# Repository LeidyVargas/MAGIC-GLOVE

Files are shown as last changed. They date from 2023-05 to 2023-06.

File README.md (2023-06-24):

Banner

# MAGIC-GLOVE
*Un proyecto que busca, que sea posible, controlar un juego con los simples movimientos de las manos;  por ello, sera usado para fines educativos y de entretenimiento, en donde mediante el juego y la diversion, las personas podran aprender.*

Nosotros Leidy Juliana Vargas Moreno, Emmanuel Bonilla Mitrotti y Juan Sebastian Torres Rodriguez; enfocados en cambiar y revolucionar la forma convencional con la que se juegan videojuegos, y que mediante la diversión se logre desarrollar una destreza y habilidad motora, además de aprender mientras se juega, vimos una necesidad que convertimos en el siguiente objetivo:

* Diseñar y construir un guante capaz de controlar un juego, mediante el transporte de señales e información, utilizando programación y circuitos electrónicos, con el fin de revolucionar la forma típica de controlar un videojuego.

De esta manera, cualquier persona podrá divertirse de una manera diferente a “presionar botones” y además, el guante también puede ser utilizado, para juegos educativos, en donde se fomente el aprendizaje, con la diversión. Solo es cuestión de adaptarlo. 

## **DIAGRAMA DE FLUJO SOLUCIÓN**
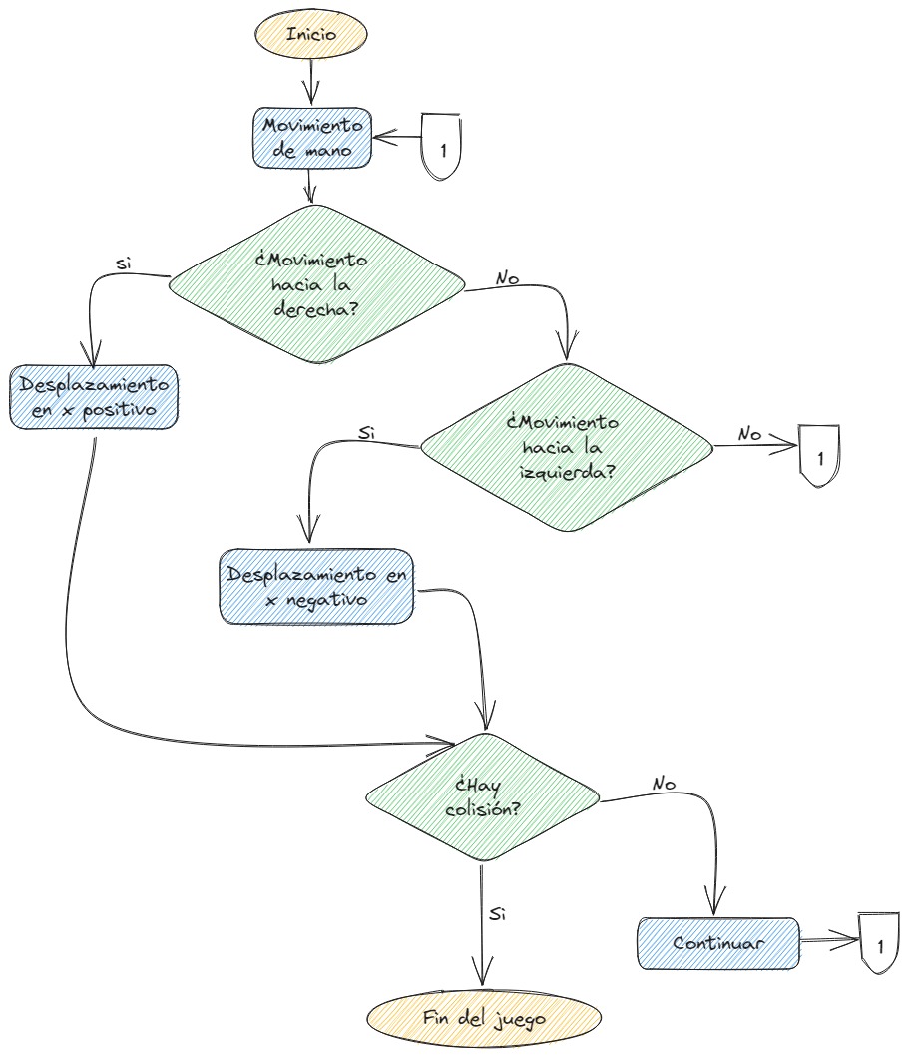
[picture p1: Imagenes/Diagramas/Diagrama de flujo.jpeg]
Diagrama de flujo Diagrama de Flujo


## **DIAGRAMA DE CAJA NEGRA**
Luego de ver el funcionamiento del guante, se establece un diagrama de cajas negras, en donde se busca definir lo que va a hacer este proyecto y lo que necesita, evaluado a su vez entradas y salidas, tanto de cada componente, como de energía.

En este primero se observa dicho diagrama, sin una tecnología definida:

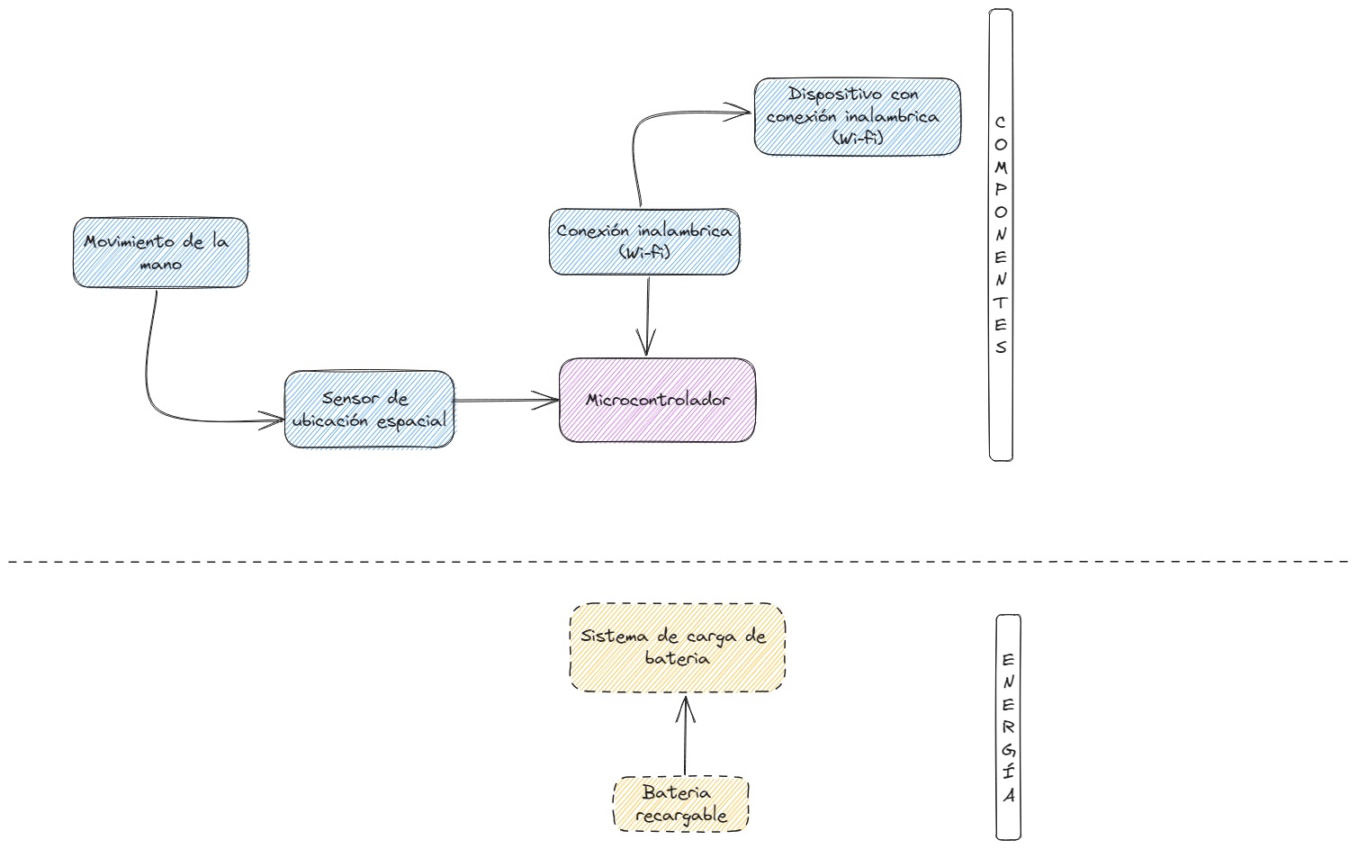
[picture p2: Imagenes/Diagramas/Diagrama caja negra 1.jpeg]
Diagrama de caja negra


Mientras que, en esta segunda imagen, se define una tecnología para cada una de las “cajas” evaluadas en el diagrama:

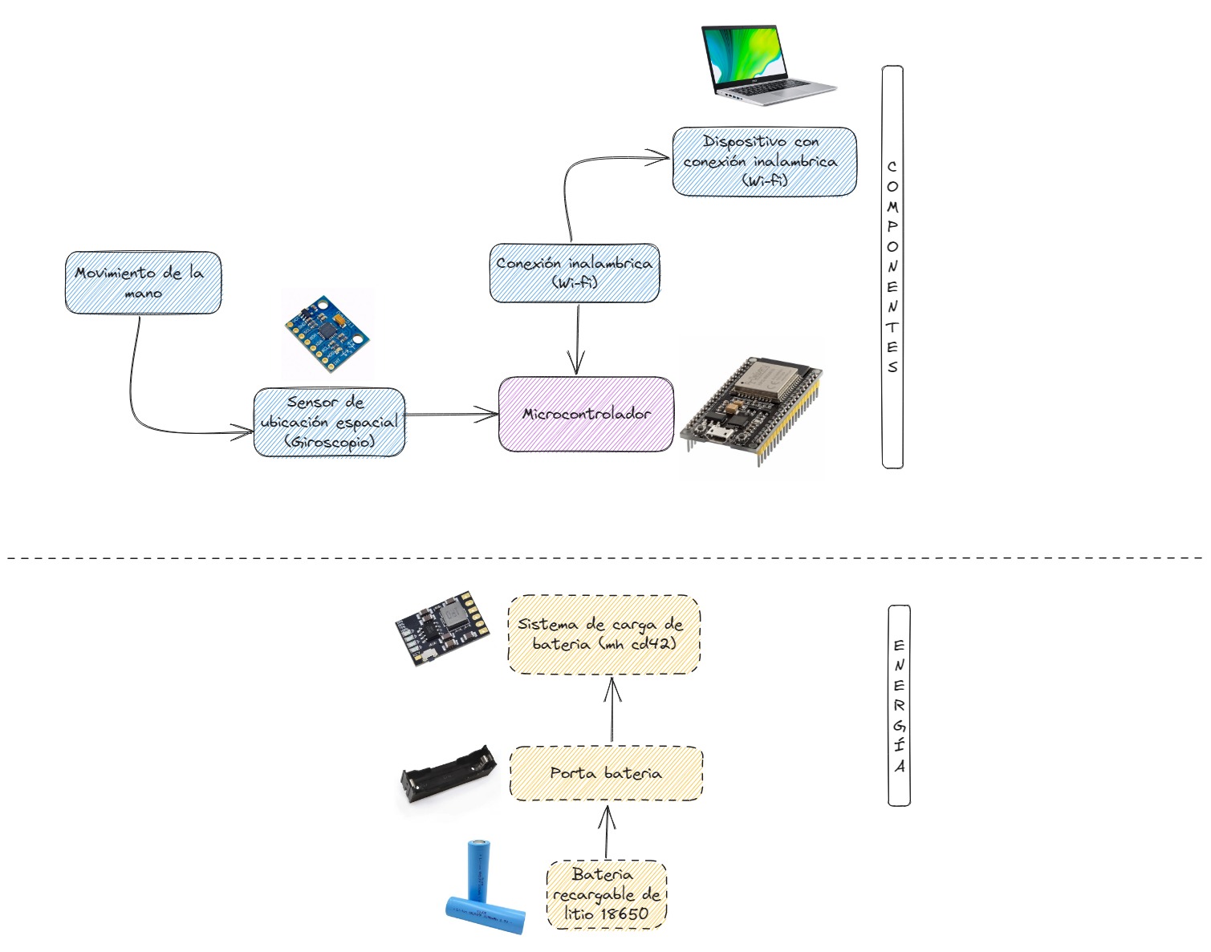
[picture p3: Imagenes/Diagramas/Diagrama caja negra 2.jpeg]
Diagrama de caja negra2


## **IMAGENES DE DISEÑOS EN EL SALON**
Conforme se avanzó en el proyecto, el profesor nos realizaba las respectivas correcciones y/o retroalimentaciones, en el tablero del salón; las cuales tenían que ver con la estructura del circuito, y se observan en las siguientes imágenes:

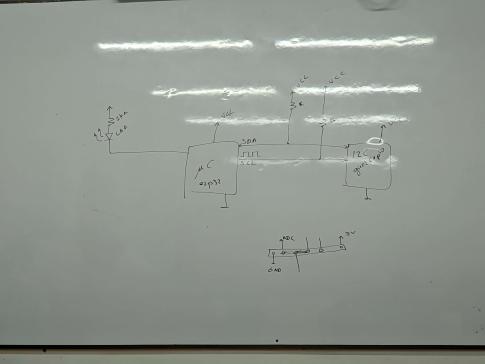
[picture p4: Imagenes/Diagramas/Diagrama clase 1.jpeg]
diseño en salon 1 Diseño en salon 1


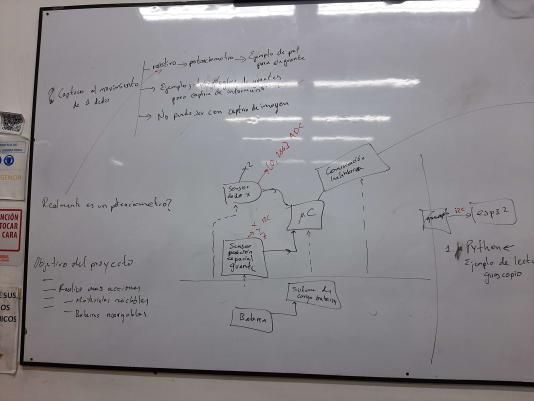
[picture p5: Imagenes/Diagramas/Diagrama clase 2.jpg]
diseño en salon 2 Diseño en salon 2


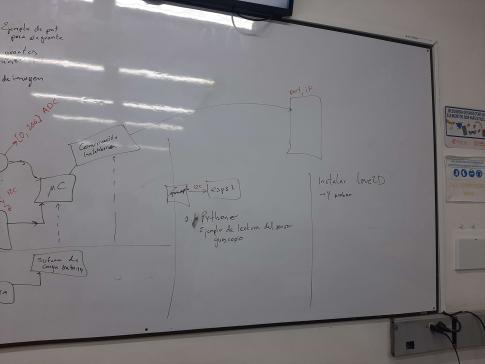
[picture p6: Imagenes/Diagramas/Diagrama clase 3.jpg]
diseño en salon 3 Diseño en salon 3


## **IMPLEMENTACIÓN**
En esta sección, se empieza  diseñar, construir y montar la parte electronica y fisica del guante, por lo cual se inicia creando el circuito que relaciona cada componente que contiene el mismo, quedando de la siguiente forma: 

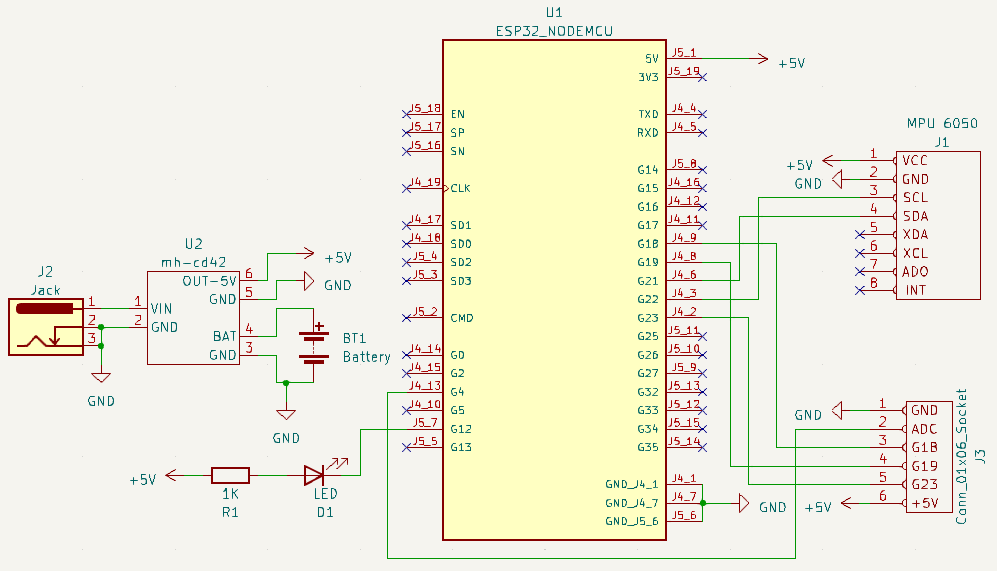
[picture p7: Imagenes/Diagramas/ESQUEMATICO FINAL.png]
Esquematico


Obtenido el circuito del proyecto, se empieza crear la placa de la PCB, en donde se realizan los caminos que conectan los componentes, asignando diferentes tamaños para señal, gnd y pines, utilizando el más grueso para el voltaje; los caminos se realizan en diferentes caras.

#### **Caminos de la cara frontal**
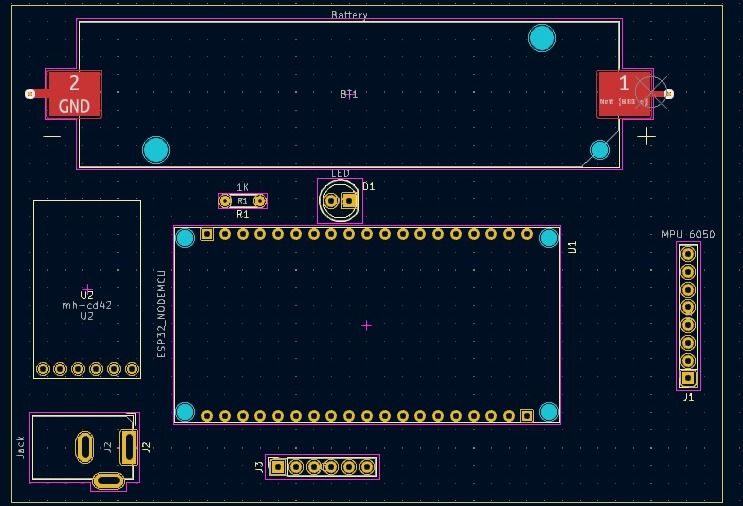
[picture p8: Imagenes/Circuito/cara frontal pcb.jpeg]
Cara Frontal

#### **Caminos de la cara trasera**
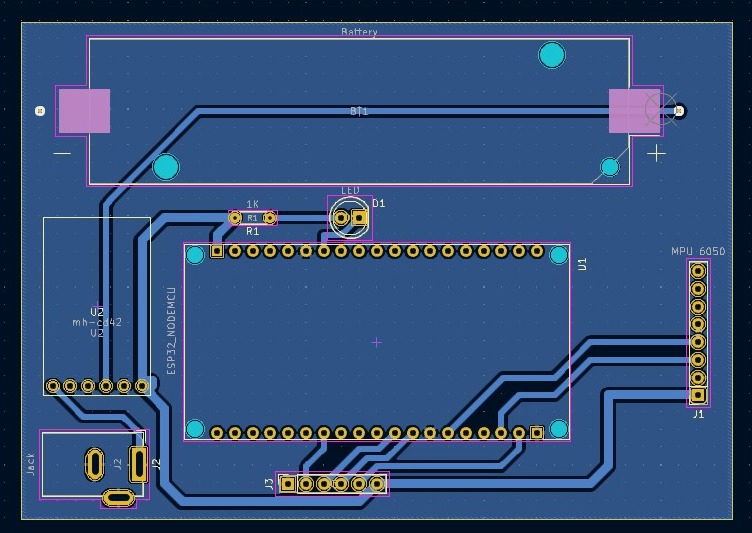
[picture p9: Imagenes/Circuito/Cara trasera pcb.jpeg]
Cara trasera


Se revisan cada uno de los posibles errores en el circuito, antes de considerarlo como resultado final, y realizado dicho proceso, se manda a construir la PCB en Yahiko electronica; 
con el archivo de los gerber que se encuentra en los archivos del GitHub como “Impresión de PCB (archivo)” . El resultado de la placa impresa se observa a continuación:

| | |
| --- |:---:|
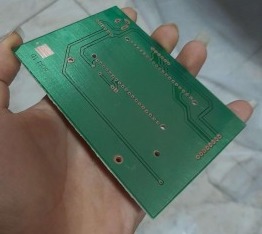
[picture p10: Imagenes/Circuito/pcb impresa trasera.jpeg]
Pcb impresa trasera
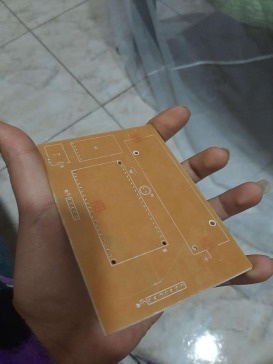
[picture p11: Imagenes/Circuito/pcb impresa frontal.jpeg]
Pcb impresa frontal
|  | |

Con la PCB, se procede a montar todo el circuito en ella, para así obtener el resultado final de la parte electrónica del proyecto.

| | |
| --- |:---:|
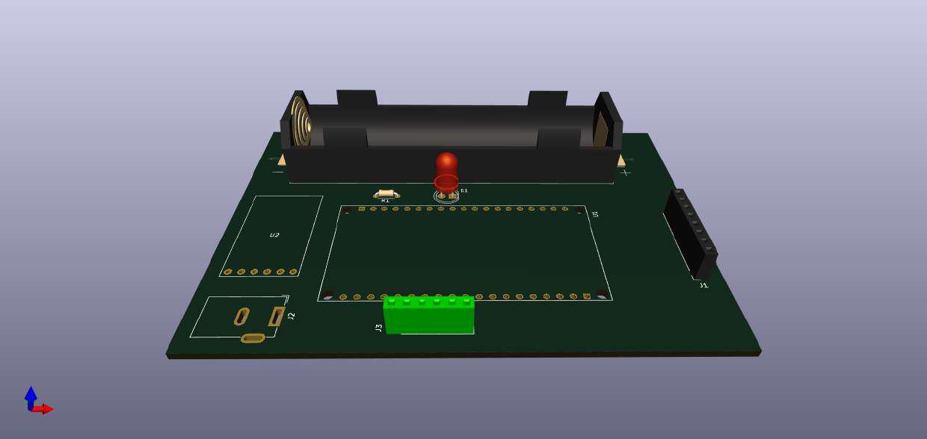
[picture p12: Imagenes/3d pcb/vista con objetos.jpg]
Pcb 3d
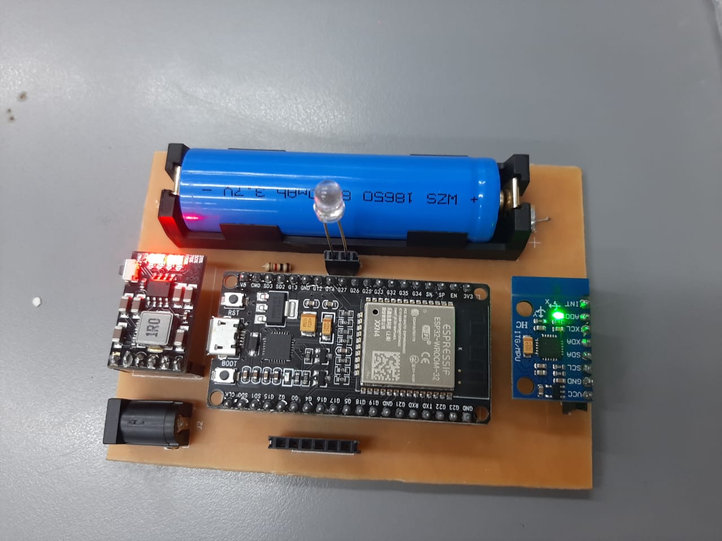
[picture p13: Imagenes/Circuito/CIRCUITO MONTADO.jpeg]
Circuito montado
| |  | 

## **PRUEBAS**

Para las pruebas, se dividieron en dos partes: De estructura y de programación:

La pruebas de estructura consisten en el corte láser, realizado para construir la caja del guante, que contiene la pcb, en donde para el primer intento de corte (archivo que se encuentra al inicio del GitHub), se genera una disminución en las medidas; lo cual se puede observar en la siguiente imagen, donde la figura de la derecha, fue en la que se alteraron las medidas, y la de la izquierda, es el resultado esperado (final). 

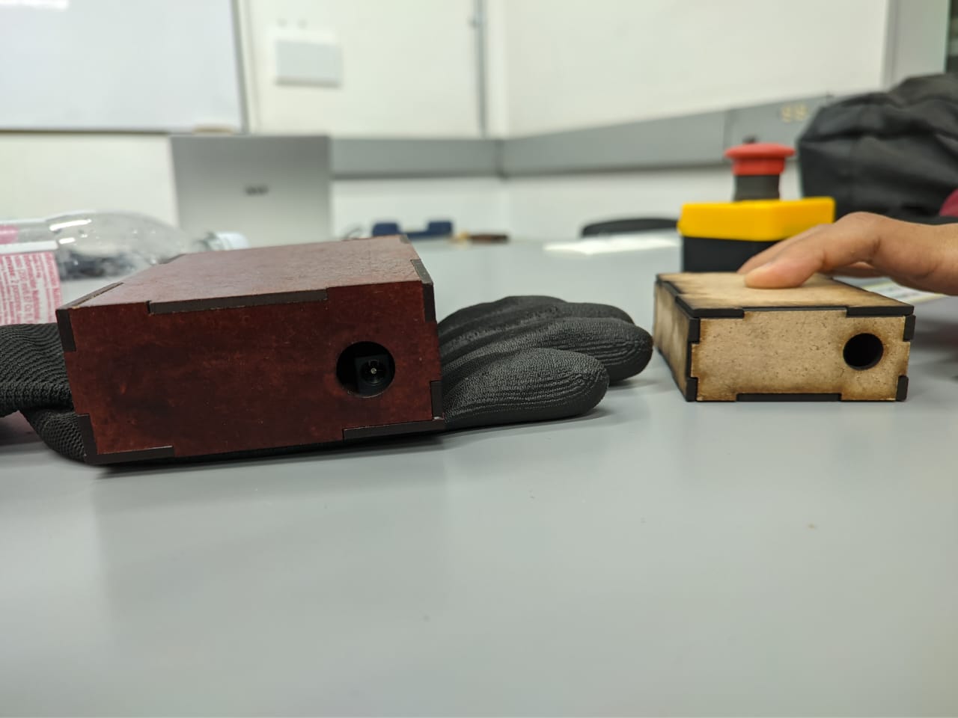
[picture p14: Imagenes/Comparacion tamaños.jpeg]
Comparacion


En el desarrollo del juego se abrió un socketUDP para poder recibir los datos del guante y asi poder mover la nave. 

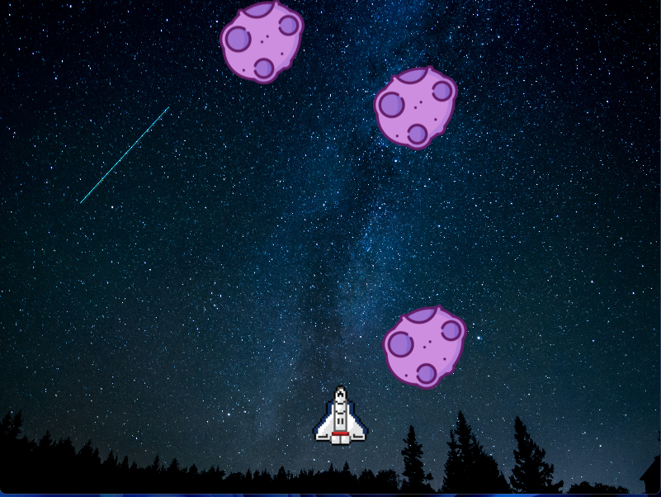
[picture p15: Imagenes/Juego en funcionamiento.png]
imagen Juego


Por otro lado, se realizaron diversas pruebas de programación, pues al principio no se recibieron correctamente los datos de movimiento del giroscopio, tal como se observa en el siguiente video; pues la nave se mueve hacia otro lado diferente del giroscopio, además de que no lograba conectarse al computador, [Link del video](./Videos/Juego%20y%20Guante%20.mp4)

Al final de las pruebas realizadas, se logra construir el guante y por tanto terminar el proyecto, el resultado y aplicación del guante, se puede observar en el siguiente video: [Link del video final. ](./Videos/PRUEBA%20DE%20FUNCIONAMIENTO.mp4)

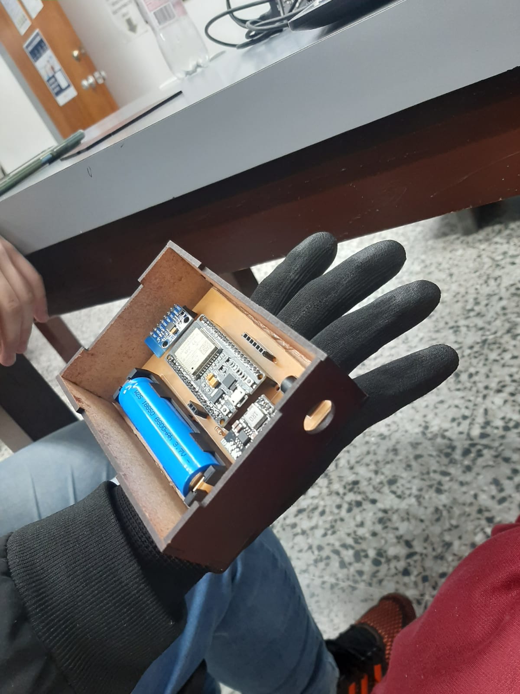
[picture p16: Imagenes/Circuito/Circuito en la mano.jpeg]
Guante en mano


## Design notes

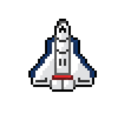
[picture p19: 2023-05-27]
Codigo-Juego/images/Nave.png

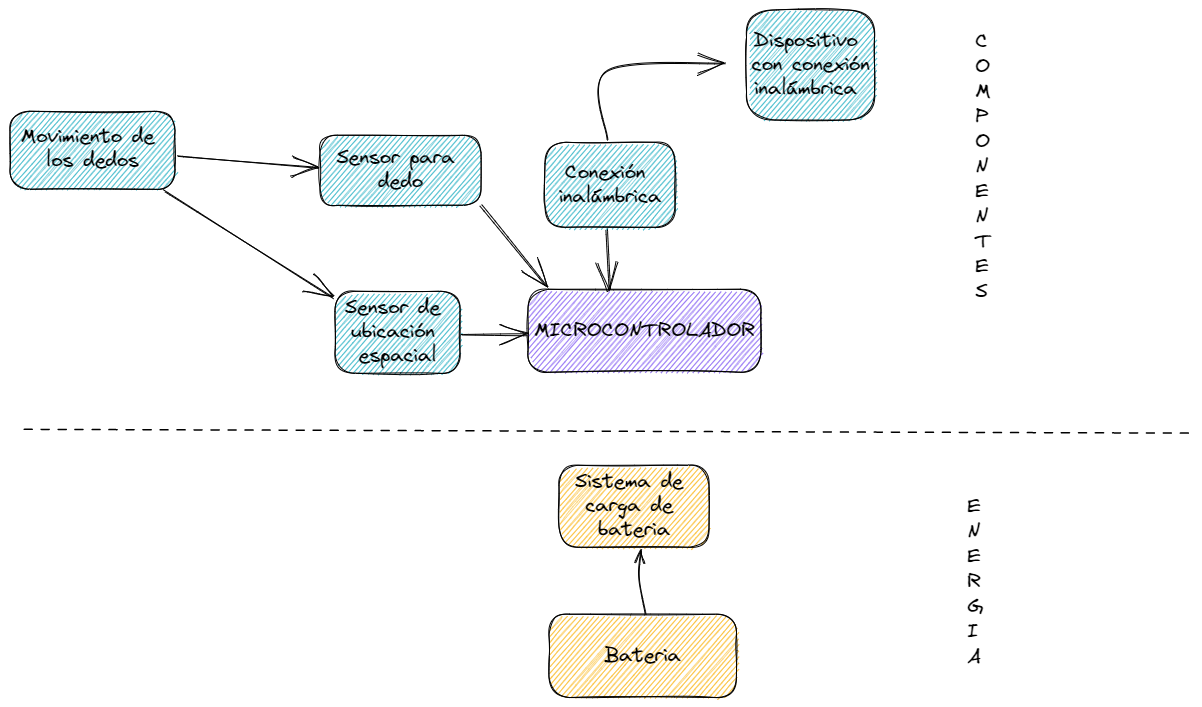
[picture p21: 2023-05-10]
Imagenes/Diagramas/DIAGRAMA CAJA NEGRA.png

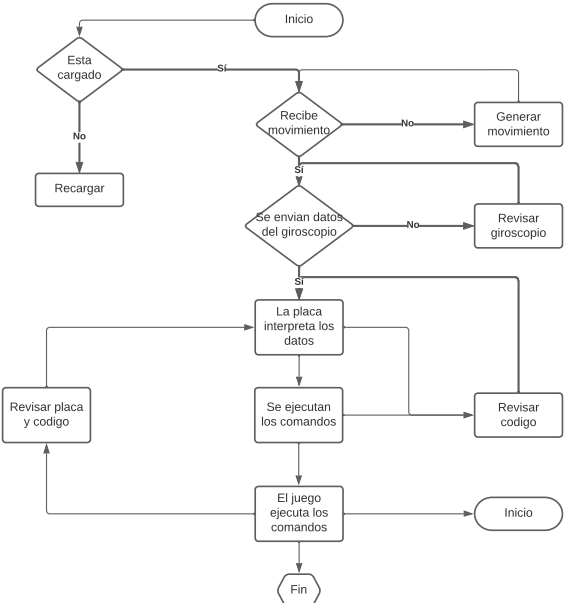
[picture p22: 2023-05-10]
Imagenes/Diagramas/DIAGRAMA DE FLUJO TECNICO.png

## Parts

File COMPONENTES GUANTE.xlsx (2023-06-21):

COMPONENTE | REFERENCIA | CANTIDAD | UNIDAD | PRECIO TOTAL | ¿Lo tenemos?
Tarjeta de desarrollo | Esp32 | 1 | $30000 | $30000 | SI
Giroscopio | MPU 6050 | 1 | $15000 | $15000 | SI
Baterias de litio recargables | 18650 | 1 | $14200 | $28000 | SI
Cargador de baterias de litio 18650 | mhcd42 (http://articulo.mercadolibre.com.co/MCO-917946237) | 1 | $9800 | $9800 | SI
Porta baterias | 18650 Soldadura SMD | 1 | $7000 | $7000 | SI
Jack power |  | 1 | $1000 | $1000 | SI
MDF | Madera mdf de 3 mm | 1 | No aplica |  | SI
TOTAL |  |  | $77000 | $90800

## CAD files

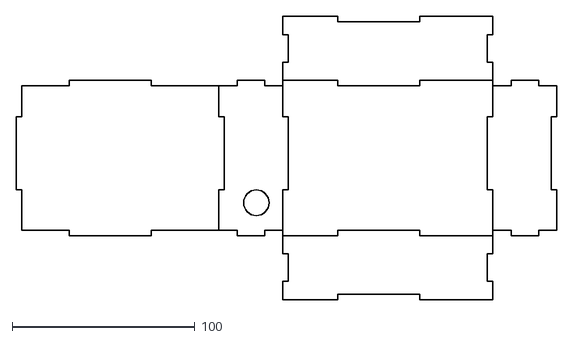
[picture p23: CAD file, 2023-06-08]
CORTE LASER.dxf
296.0 x 155.0

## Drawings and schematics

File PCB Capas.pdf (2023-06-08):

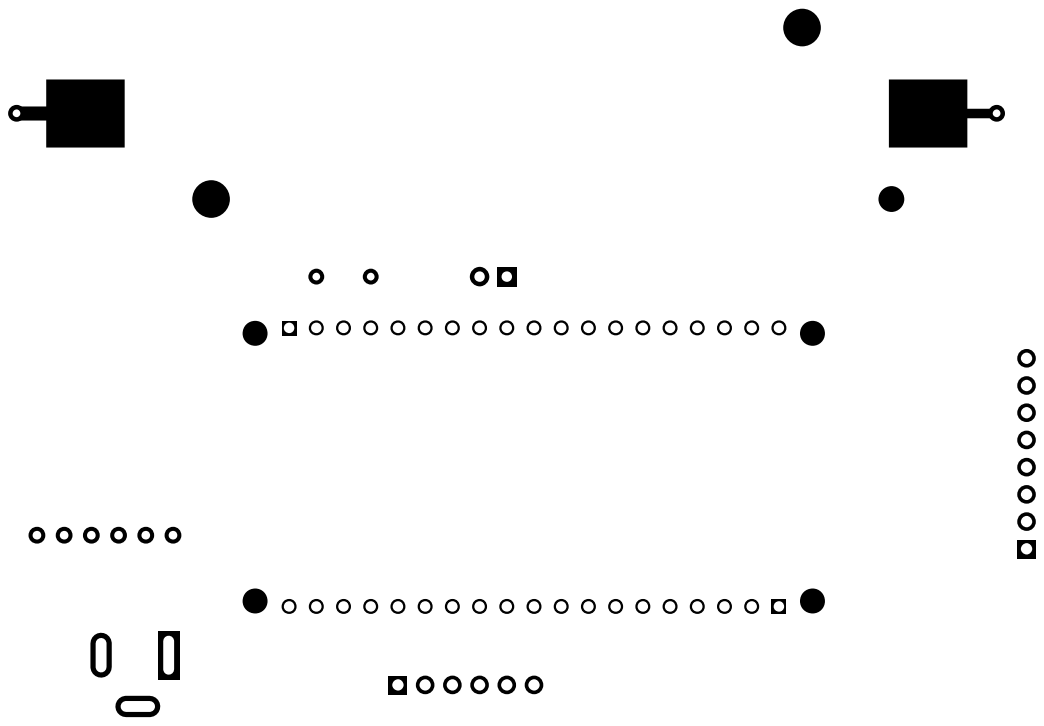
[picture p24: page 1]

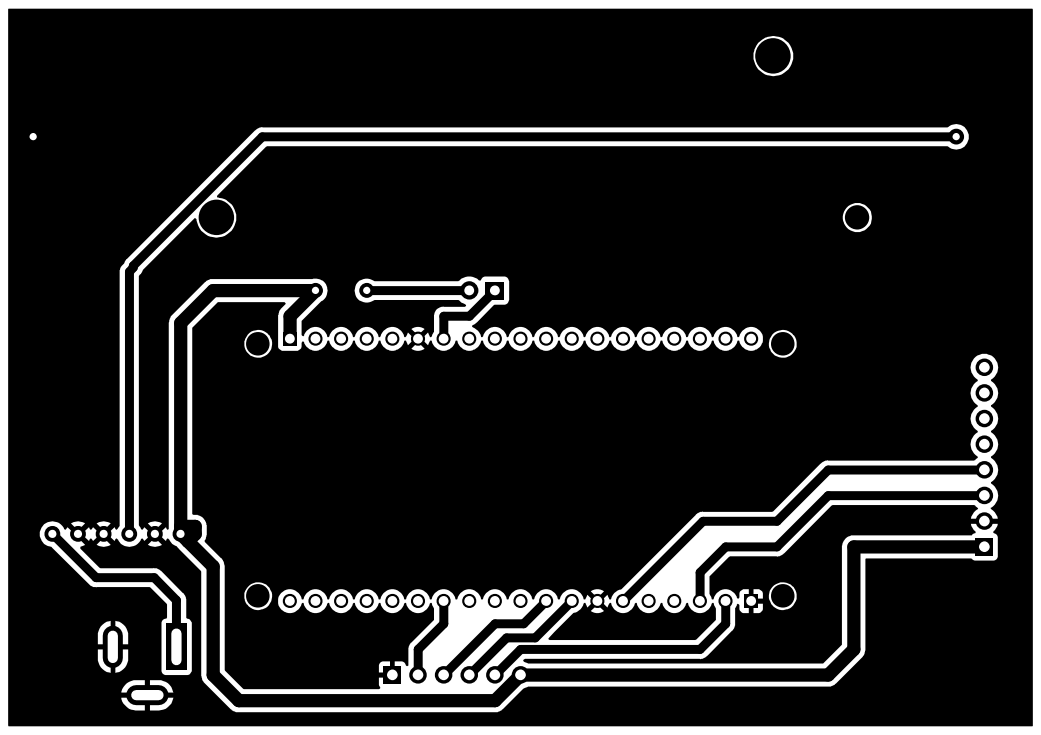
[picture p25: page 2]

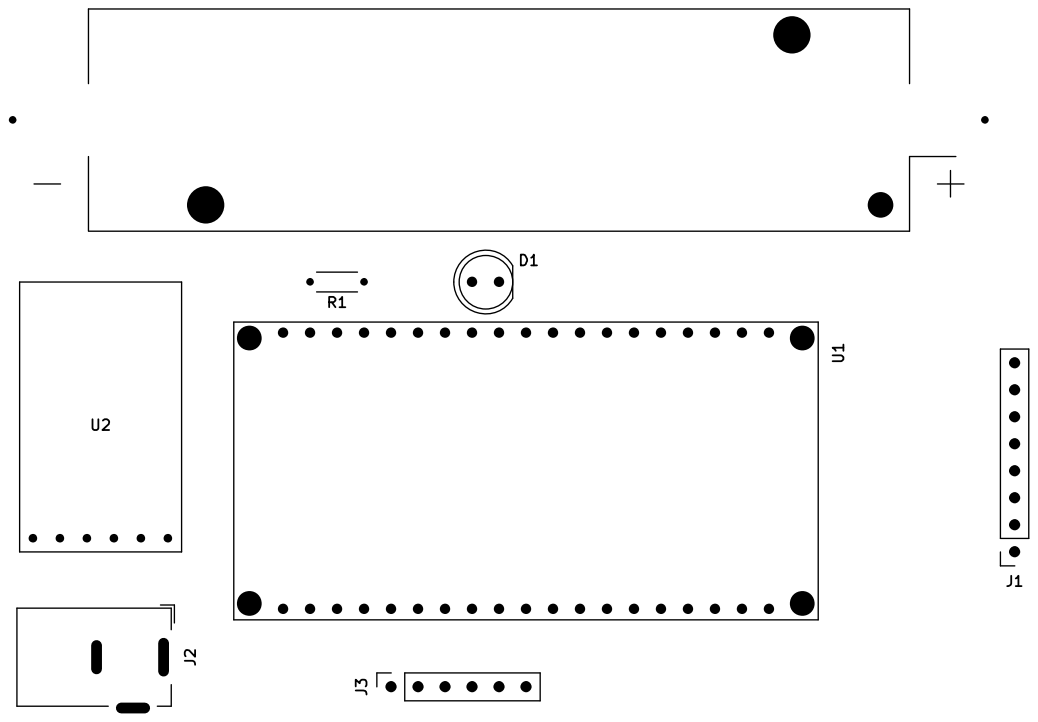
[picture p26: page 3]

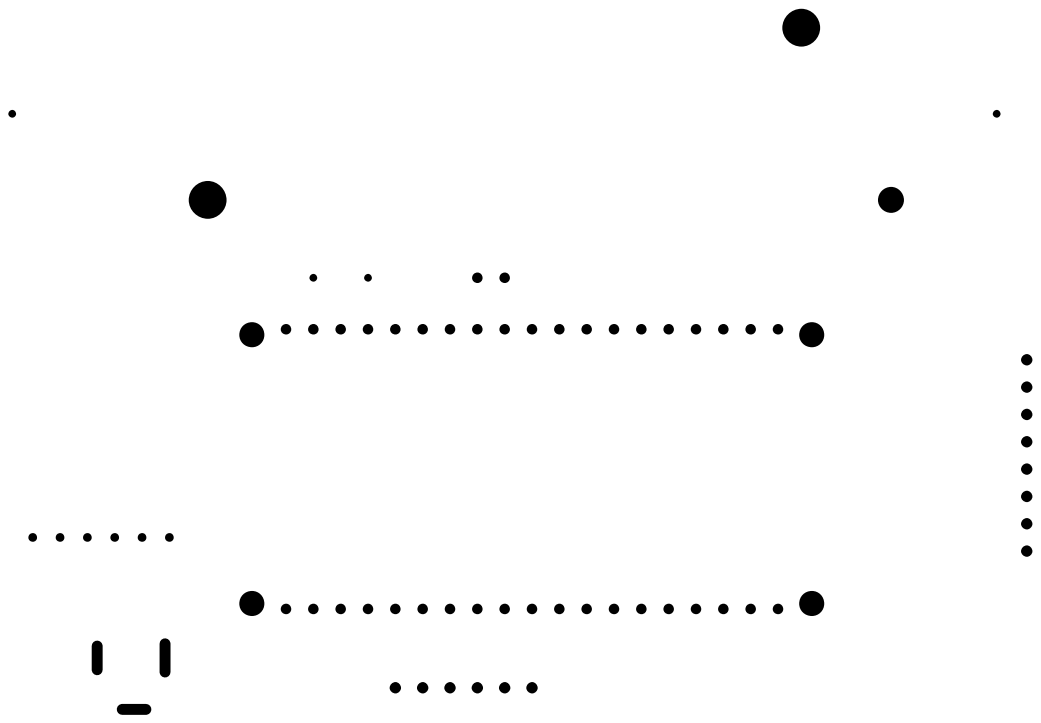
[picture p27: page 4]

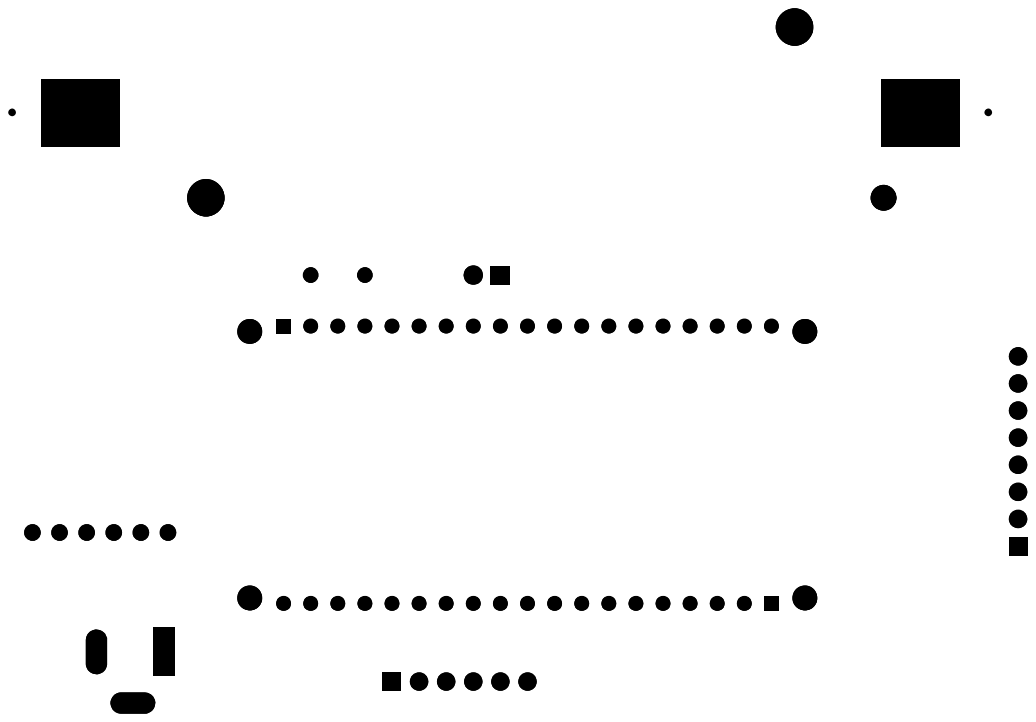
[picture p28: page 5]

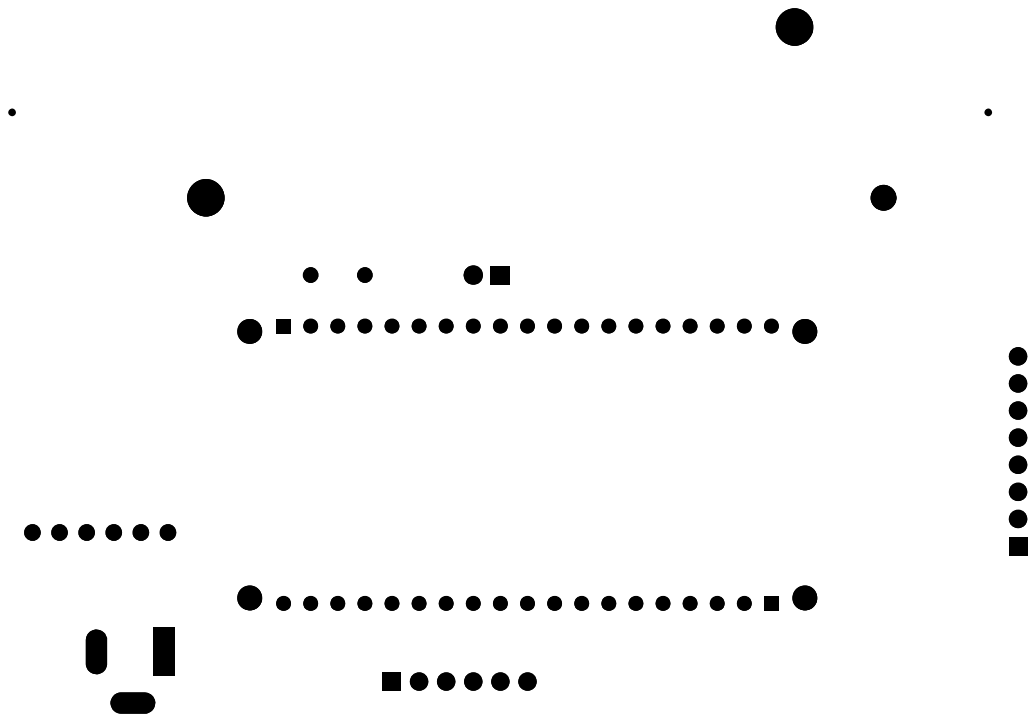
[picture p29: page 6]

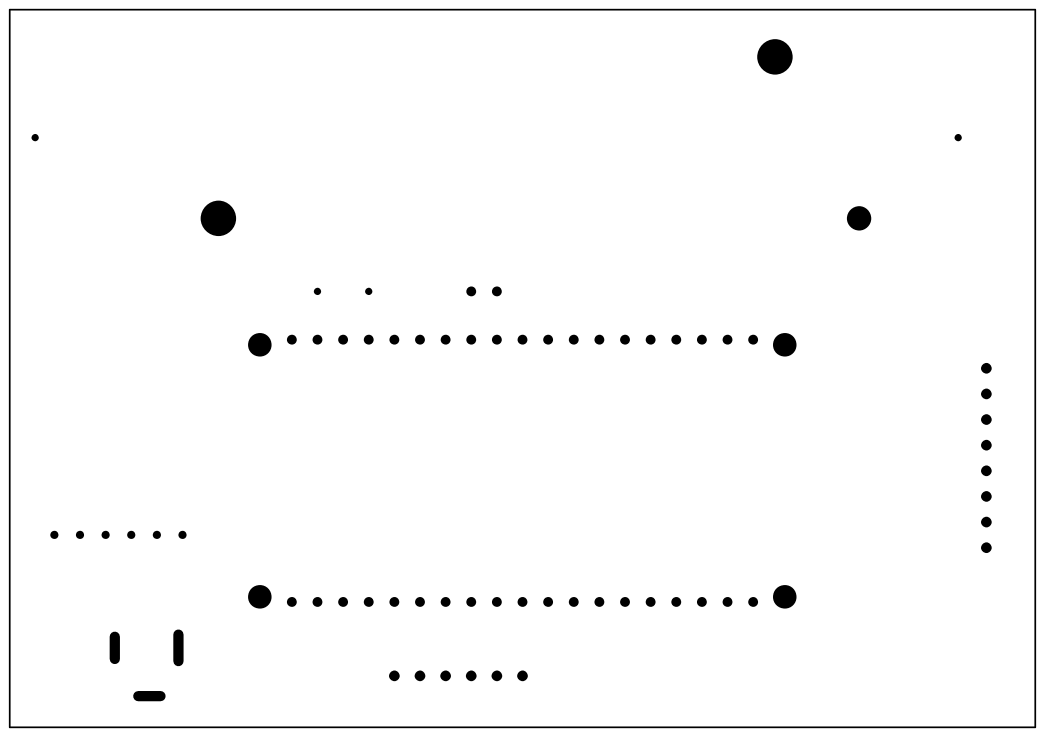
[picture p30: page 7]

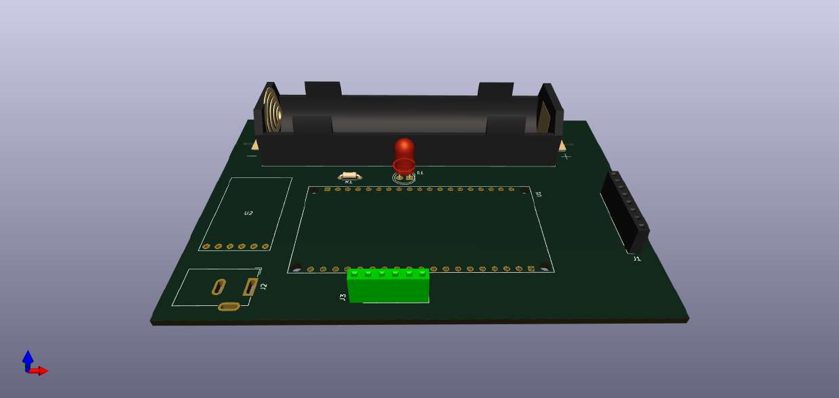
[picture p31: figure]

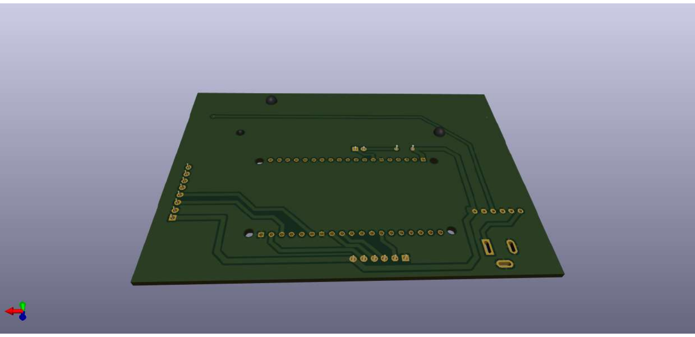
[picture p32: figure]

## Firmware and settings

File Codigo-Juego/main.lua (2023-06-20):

socket = require("socket")
Udp = socket.udp()
Udp:setsockname('192.168.12.8', 12345)
Udp:settimeout(0)

function love.load()
  -- carga e inicio de variables
  
  Object = require 'classic'
  require 'asteroide'
  -- controles
  
  gameOver = love.graphics.newImage('images/game-over.png')

  windowHeight = love.graphics.getHeight()
  windowWidth = love.graphics.getWidth()

  background = love.graphics.newImage('images/Cielo-estrellado.jpg')
  backgroundW = background:getWidth()
  backgroundH = background:getHeight()

  nave = love.graphics.newImage('images/Nave.png')
  naveWidth = 125
  naveHeight = 125
  
  posicionX = 350
  posicionY = 450
  
  hitBoxX = naveWidth/2 
  hitBoxY = naveHeight/2
  hitBoxRadio = 25
 
  velocidadJugador = 350
  velocidadAsteroide = 350  

  text = "ejemplo"

  a = asteroide()
  b = asteroide()
  c = asteroide()
  d = asteroide()
  e = asteroide()
  f = asteroide()
  g = asteroide()
end

function love.update(dt)
  -- logica del juego se actualiza constantemente

  --**********************************************************
  -- local data, msg_or_ip, port_or_nil = Udp:receivefrom()
  -- text = tostring(data)
  --******************************************************************

  -- asteroides
  if (checkColision(a) or checkColision(b) or checkColision(c) or checkColision(d) or checkColision(e) or checkColision(f) or checkColision(g)) then 
    colision = true
  else 
    colision = false
  end
  if not colision then
    -- movimientos de la nave
    movimiento = controlesUpdate()
    posicionX = posicionX + (movimiento * velocidadJugador) * dt

    if love.keyboard.isDown("right") then
      posicionX = posicionX + velocidadJugador * dt
    end
    if love.keyboard.isDown("left") then
      posicionX = posicionX - velocidadJugador * dt
    end

    -- limites de la nave
    if posicionX < 0 then
      posicionX = 0
      end 
    if posicionX + naveWidth > windowWidth then
      posicionX = windowWidth - naveWidth
    end
    -- update asteroides
    a.update(a, dt * 1)
    b.update(b, dt * 1)
    c.update(c, dt * 1.1)
    d.update(d, dt * 1.2)
    e.update(e, dt * 0.9)
    f.update(f, dt * 1.1)
    g.update(g, dt * 0.9)
  
    if a.y > windowHeight then
     a = asteroide() 
    end
  
    if b.y > windowHeight then
      b = asteroide()
     end

    if c.y > windowHeight then
     c = asteroide()
    end

    if d.y > windowHeight then
     d = asteroide()
    end

    if e.y > windowHeight then
     e = asteroide()
    end

    if f.y > windowHeight then
     f = asteroide()
    end

    if g.y > windowHeight then
     g = asteroide()
    end
  end

end

function love.draw()
  -- dibujar y mostrar en pantalla (se ejecuta despues del update)
  love.graphics.draw(background, 0, 0, 0, windowWidth/backgroundW, windowHeight/backgroundH)
  if colision then
    love.graphics.draw(gameOver, 140, 0,0, 0.5,0.5)
  end
   -- movimiento nave
  love.graphics.draw(nave, posicionX, posicionY)
  -- love.graphics.circle("line", hitBoxX+posicionX, hitBoxY + posicionY, hitBoxRadio) --hitbox nave
  --love.graphics.print(text, 200, 450 )
  --asteroides
  a.draw(a)
  b.draw(b)
  c.draw(c)
  d.draw(d)
  e.draw(e)
  f.draw(f)
  g.draw(g)
end

function checkColision(obj)
  local dist = math.sqrt(((obj.x+obj.hitboxX) - (hitBoxX+posicionX))^2  + ((obj.hitboxY + obj.y) - (hitBoxY + posicionY))^2)
  return dist <= obj.hitboxRadio + hitBoxRadio
end 

function controlesUpdate()
  local x = 0
	local data, msg_or_ip, port_or_nil = Udp:receivefrom()
  x = tonumber(data)
	if data then
		if x < -5 then
			return -1
		end
		if x > 5 then 
			return 1
		end
		if x >= -5 and x<= 5 then
			return 0 
		end
  else
    return 0
	end
end
function love.keypressed(key)
  if key == "r" then
      love.event.quit("restart")
  end
end

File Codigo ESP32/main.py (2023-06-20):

# Este programa se diseña por Sebastian Torres
# para el proyecto Magic-glove
# taller de electronica unal 2023-1

#Modulos
import usocket
import mpu6050
import time
import math
from machine import Pin, I2C
import network


#conectar wifi
wlan = network.WLAN(network.STA_IF)
wlan.active(True)
# funcion para conectar al wifi
def connectWifi(ssid, pwd):
    while not wlan.isconnected():
        print('connecting to network...')
        time.sleep(1)
        if wlan.status() == 1001:
            pass
        else:
            wlan.connect(ssid, pwd)
#llamado a la función para conectarse
if not wlan.isconnected():
    connectWifi("MagicGlove","aeiouaei")
else:
    print('network config:', wlan.ifconfig())
    
# Crear socket UDP
server = usocket.socket(usocket.AF_INET, usocket.SOCK_DGRAM)
serverAdressPort = ("192.168.12.8", 12345)
#función para enviar datos por el socket
def sendUDP(data):
    try:
        server.sendto(str.encode(data), serverAdressPort)
    except:
        print("error send")
        
# Usar Giroscopio
i2c = I2C(scl = Pin(22), sda = Pin(21))
mpu = mpu6050.accel(i2c)
#funcion para pasar de raw a grados
def conversion(x):
    return round(x * 250 / 32767, 2)
#lectura de datos y programa principal
while True:
    temps = (mpu.get_values())
    gyroX = temps ["GyX"]
    gyroY = temps ["GyY"]
    gyroZ = temps ["GyZ"]
    tmp = temps ["Tmp"]
    gradosX = conversion(gyroX)
    gradosY = conversion(gyroY)
    gradosZ = conversion(gyroZ)
    print("grados x: ", gradosX)
    print("grados y: ", gradosY)
    print("grados z: ", gradosZ)
    print("temperatura: ", tmp)
    print()
    time.sleep_ms(10)
    sendUDP(str(gradosY))

    

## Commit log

2023-05-10 DIAGRAMA DE FLUJO GUANTE🌟😎
    En este documento se observa un diagrama, que describe el funcionamiento del guante y lo que se espera que haga, cuando se le de una orden o se le envíen comandos; además de que va evaluando cada pro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
2023-05-10 DIAGRAMA DE FLUJO DEL JUEGO 🌟😎
    En este documento se describe, mediante un diagrama, de funcionamiento del videojuego, una vez recibidos los comandos del guante.
2023-05-10 DIAGRAMAS DE CAJA NEGRA 📦🌟
    En esta sección, se puede observar un diagrama en el que únicamente se definen las funcione del guante, lo que se espera recibir y lo que debe salir, además de que da una idea de la relación y/o cone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
2023-05-10 INVENTARIO DE COMPONENTES 🌟📋
    Una vez seleccionada la tecnología y componentes adecuados, se realiza la cotización de los mismos, para la planeación del proyecto. En este documento se relaciona descripción, cantidad, referencia, 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
    [COMPONENTES GUANTE (2).xlsx]
2023-05-10 CIRCUITO (versión 1) 🌟🤖
    En la imagen, se encuentra el primer esquemático del proyecto, que e puede someter a posibles actualizaciones o modificaciones para llegar al circuito final.
2023-06-08 EQUEMATICO FINAL 🤖🌟
    Luego de unas retroalimentación por parte el docente y de aplicar unas correcciones al esquema inicial; se define el que se observa en la imagen siguiente, como el esquemático final del proyecto.
2023-06-08 PLACA PARA EL DISEÑO DE LA PCB 🌟
    En la imagen se puede observar la placa diseñada en la plataforma KiCad, que posteriormente fue enviada a fabricación, para lucir como se observa en el documento pdf.
2023-06-08 IMPRESION DE LA PCB (archivo)😎
    En este archivo, se encuentran las distintas caras trabajadas en KiCad y capas solicitadas por los fabricantes, para la construcción de la PCB, junto con una vista 3D de la idea final.
2023-06-08 POSTER PARA PATICIPACION EN EL ENCUENTRO "INGENIA FUTURO" 🤖🌟
    En el documento, se observa el poster diseñado, para inscribir el proyecto Magic-Glove, y participar del evento Ingenia futuro y así dar a conocer el proyecto, a muchas mas personas.
2023-06-08 CIRCUITO EN FISICO 😎🌟
    Una vez impresa la PCB, se soldán cada uno de lo componentes a esta, utilizando regletas macho y hembra, para poder separar los componentes de la PCB; y al finalizar dicho proceso, se obtiene el resu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
2023-06-08 REALIZACION DE PRUEBAS 😎🌟
    Al construir él guante en físico, con su respectivo circuito y videojuego, se empiezan a realizar pruebas de funcionamiento, para ver si el guante realmente controla el juego. Aunque en el siguiente 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
2023-06-08 PLANO PARA CORTE LASER 🌟✂️
    En el documento adjunto, se observa el archivo, enviado para el corte laser, se la caja, donde se ubica el circuito. Con las medidas necesarias, para un encaje perfecto.
    [CORTE LASER.dxf]
2023-06-20 organización archivo y adición readme
    [COMPONENTES GUANTE (2).xlsx, COMPONENTES GUANTE.xlsx]
2023-06-20 INVENTARIO DE COMPONENTES DEFINITIVO🌟📋
    En esta sección, se encuentra el inventario final de los componentes, en el que se incluyen la totalidad de elementos y materiales, empelados para la elaboración del guante.
    [COMPONENTES GUANTE (2).xlsx]
